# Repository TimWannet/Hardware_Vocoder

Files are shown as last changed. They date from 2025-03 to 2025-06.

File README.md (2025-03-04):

# Hardware_Vocoder

## Table of Contents
- [Introduction](#introduction)
- [Features](#features)
- [Installation](#installation)
- [Usage](#usage)
- [Contributing](#contributing)
- [License](#license)

## Introduction
Coming soon

## Features
Coming soon

## Installation
1. Clone the repository:
    ```bash
    git clone https://github.com/yourusername/Hardware_Vocoder.git
    ```
2. Navigate to the project directory:
    ```bash
    cd Hardware_Vocoder
    ```

3. Install [PlatformIO IDE](https://platformio.org/install/ide?install=vscode) for Visual Studio Code.

4. (Linux only) Install UDEV Rules

5. Open the project in Visual Studio Code.

6. Configure the `platformio.ini` file in the project directory with the following content:
    ```ini
    [env:teensy40]
    platform = teensy
    board = teensy41
    framework = arduino
    ```
7. Connect your Teensy board to your computer.

8. Build and upload the project to the Teensy board:
    ```bash
    pio run --target upload
    ```
9. Verify the installation by checking the serial monitor for output from the Teensy board.

## Usage
Coming soon 

## Contributing
Coming soon

## License
The licence for this project is still being

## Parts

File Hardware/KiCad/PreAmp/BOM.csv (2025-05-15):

Comment | Designator | Footprint | JLCPCB Part+ACM-(optional)
INA217AIDWR | U2 | INA217:DW16 | C1849416
TLV2371DBV | U1 | Package+AF8-TO+AF8-SOT+AF8-SMD:SOT+AC0-23+AC0-5 | C55940
27R | R5 | Capacitor+AF8-SMD:C+AF8-0805+AF8-2012Metric | C17594
2.2K | +ACI-R3 | R4+ACI- | Capacitor+AF8-SMD:C+AF8-0805+AF8-2012Metric | C17520
12K | R2 | Capacitor+AF8-SMD:C+AF8-0805+AF8-2012Metric | C2907225
33K | R1 | Capacitor+AF8-SMD:C+AF8-0805+AF8-2012Metric | C17633
0.1uF | +ACI-C3 | C4+ACI- | Capacitor+AF8-Tantalum+AF8-SMD:CP+AF8-EIA+AC0-3216+AC0-18+AF8-Kemet+AC0-A | C7173
47uF | +ACI-C1 | C2+ACI- | Capacitor+AF8-SMD:C+AF8-1206+AF8-3216Metric | C76659

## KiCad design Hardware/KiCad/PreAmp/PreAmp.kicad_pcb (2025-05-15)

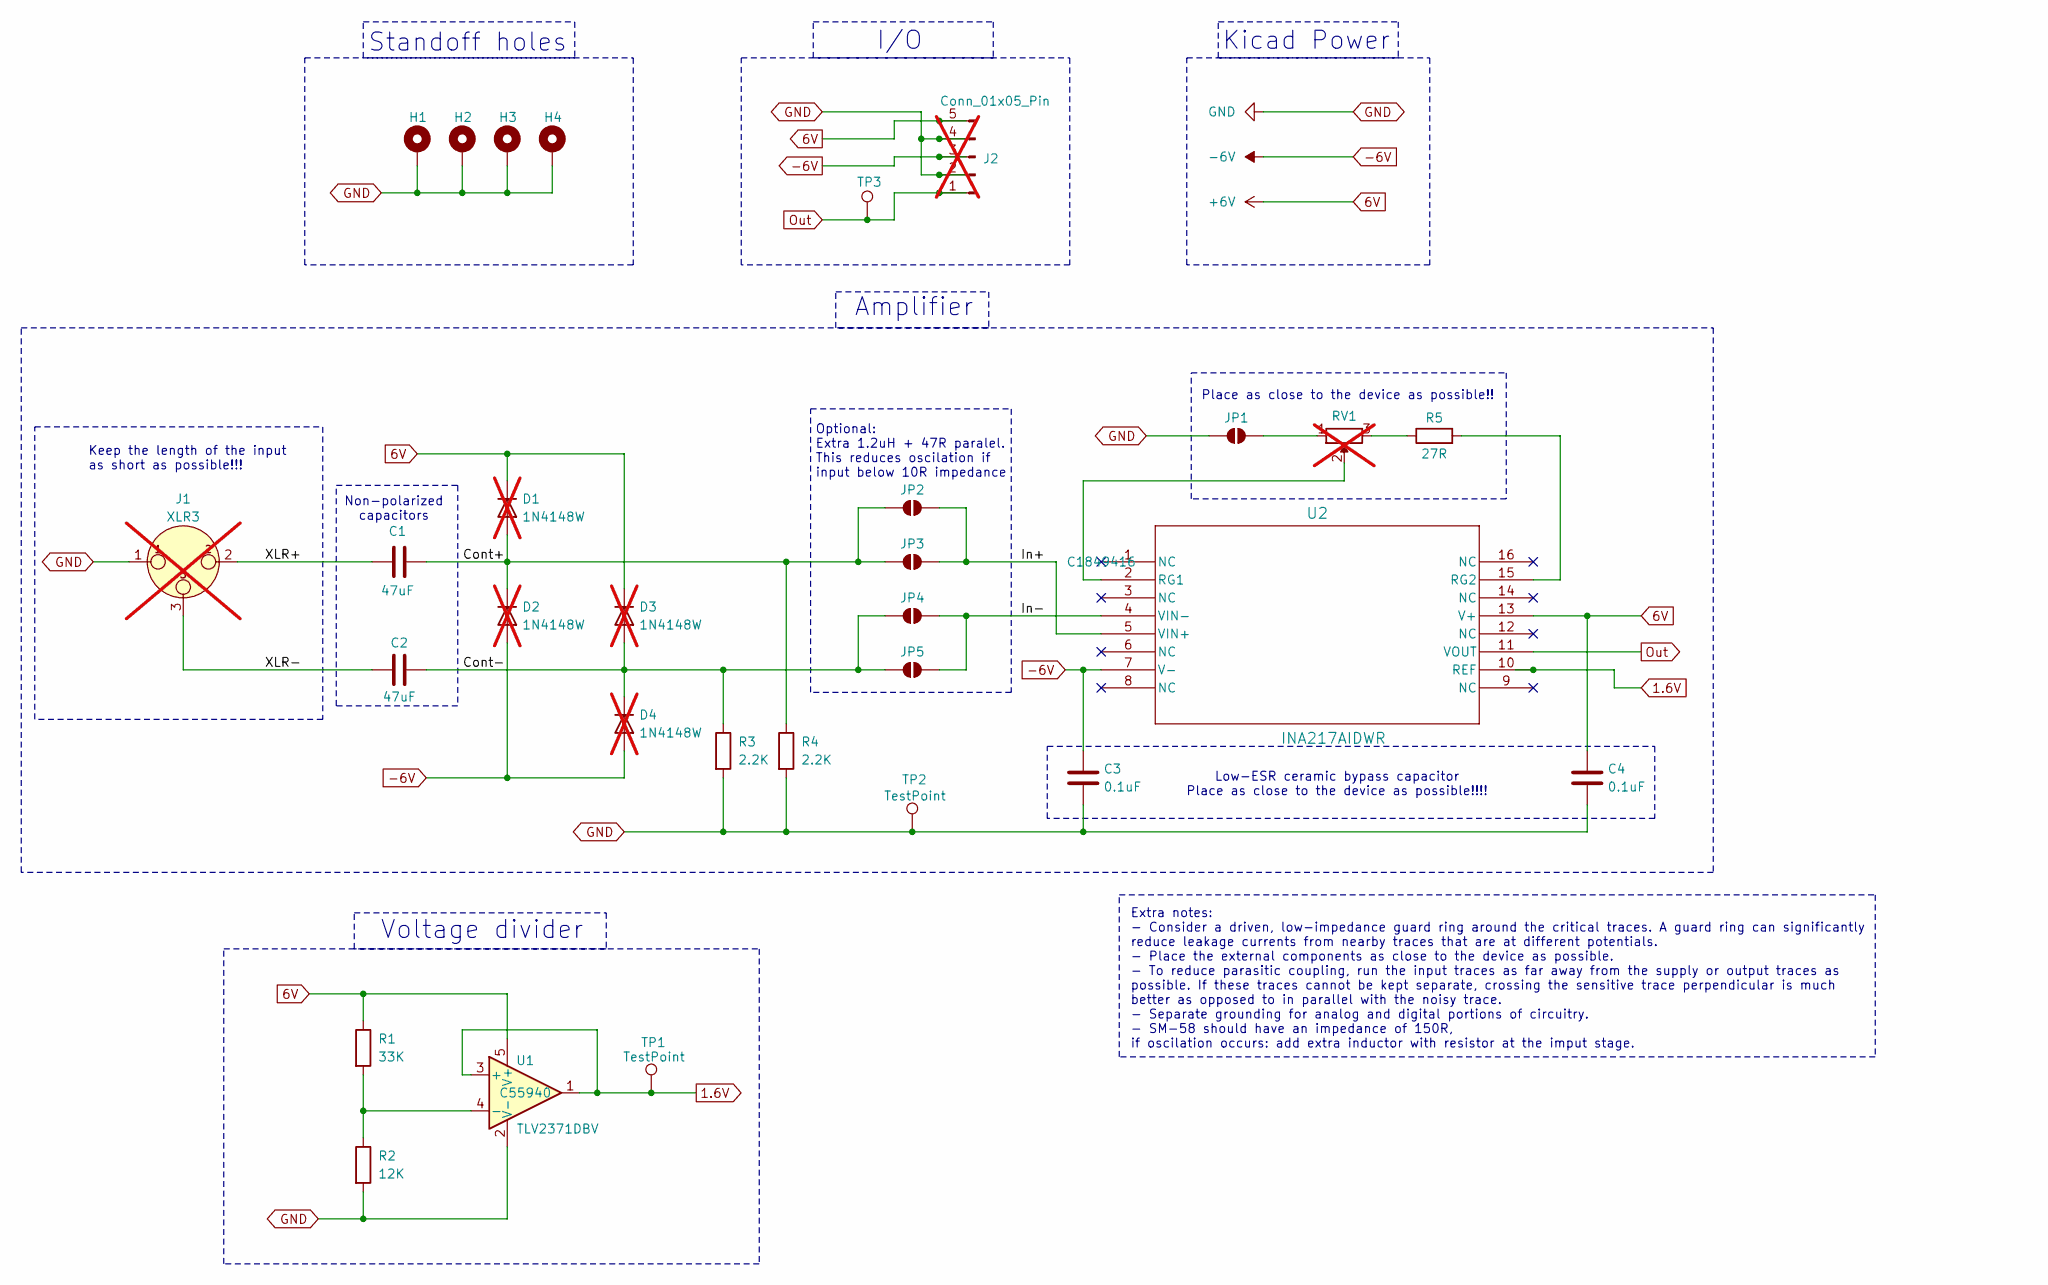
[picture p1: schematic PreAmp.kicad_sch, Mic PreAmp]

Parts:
C1, C2: 47uF; C_1206_3216Metric; LCSC PN C76659
C3, C4: 0.1uF; CP_EIA-3216-18_Kemet-A; LCSC PN C7173
D1, D2, D3, D4: 1N4148W; D_DO-35_SOD27_P7.62mm_Horizontal; not fitted
H1, H2, H3, H4: MountingHole_Pad; MountingHole_3.2mm_M3_DIN965_Pad_TopBottom
J1: XLR3; Jack_XLR_Neutrik_NC3FAAV-0_Vertical; not fitted
J2: Conn_01x05_Pin; PinHeader_1x05_P2.54mm_Vertical; not fitted
JP1, JP2, JP3, JP4, JP5: SolderJumper_2_Open; SolderJumper-2_P1.3mm_Open_Pad1.0x1.5mm
R1: 33K; C_0805_2012Metric; LCSC PN C17633
R2: 12K; C_0805_2012Metric; LCSC PN C2907225
R3, R4: 2.2K; C_0805_2012Metric; LCSC PN C17594
R5: 27R; C_0805_2012Metric; LCSC PN C17594
RV1: R_Potentiometer; Potentiometer_Alpha_RD901F-40-00D_Single_Vertical; not fitted
TP1, TP2, TP3: TestPoint; TestPoint_Pad_D2.0mm
U1: TLV2371DBV; SOT-23-5; LCSC PN C55940
U2: INA217AIDWR; DW16; LCSC PN C1849416

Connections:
1.6V: TP1.1, U1.1, U1.3 (+), U2.10 (REF)
6V: C4.1, D1.1 (K), D3.1 (K), J2.5, R1.1, U1.5 (V+), U2.13 (V+)
-6V: C3.1, D2.2 (A), D4.2 (A), J2.3, U2.7 (V-)
/Cont+: C1.2, D1.2 (A), D2.1 (K), JP2.2 (B), JP3.2 (B), R4.1
/Cont-: C2.2, D3.2 (A), D4.1 (K), JP4.2 (B), JP5.2 (B), R3.1
/In+: JP2.1 (A), JP3.1 (A), U2.5 (VIN+)
/In-: JP4.1 (A), JP5.1 (A), U2.4 (VIN-)
/XLR+: C1.1, J1.2
/XLR-: C2.1, J1.3
GND: C3.2, C4.2, H1.1, H2.1, H3.1, H4.1, J1.1, J2.2, J2.4, JP1.2 (B), R2.2, R3.2, R4.2, TP2.1, U1.2 (V-)
unnamed: JP1.1 (A), RV1.1
unnamed: R5.1, RV1.3
unnamed: R1.2, R2.1, U1.4 (-)
unnamed: RV1.2, U2.2 (RG1)
unnamed: R5.2, U2.15 (RG2)
Out: J2.1, TP3.1, U2.11 (VOUT)

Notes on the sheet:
Optional: Extra 1.2uH + 47R paralel. This reduces oscilation if input below 10R impedance
Standoff holes
Extra notes: - Consider a driven, low-impedance guard ring around the critical traces. A guard ring can significantly reduce leakage currents from nearby traces that are at different potentials. - Place the external components as close to the device as possible. - To reduce parasitic coupling, run 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
Low-ESR ceramic bypass capacitor Place as close to the device as possible!!!!
Voltage divider
Place as close to the device as possible!!
Amplifier
Kicad Power
Non-polarized capacitors
Keep the length of the input as short as possible!!!
I/O

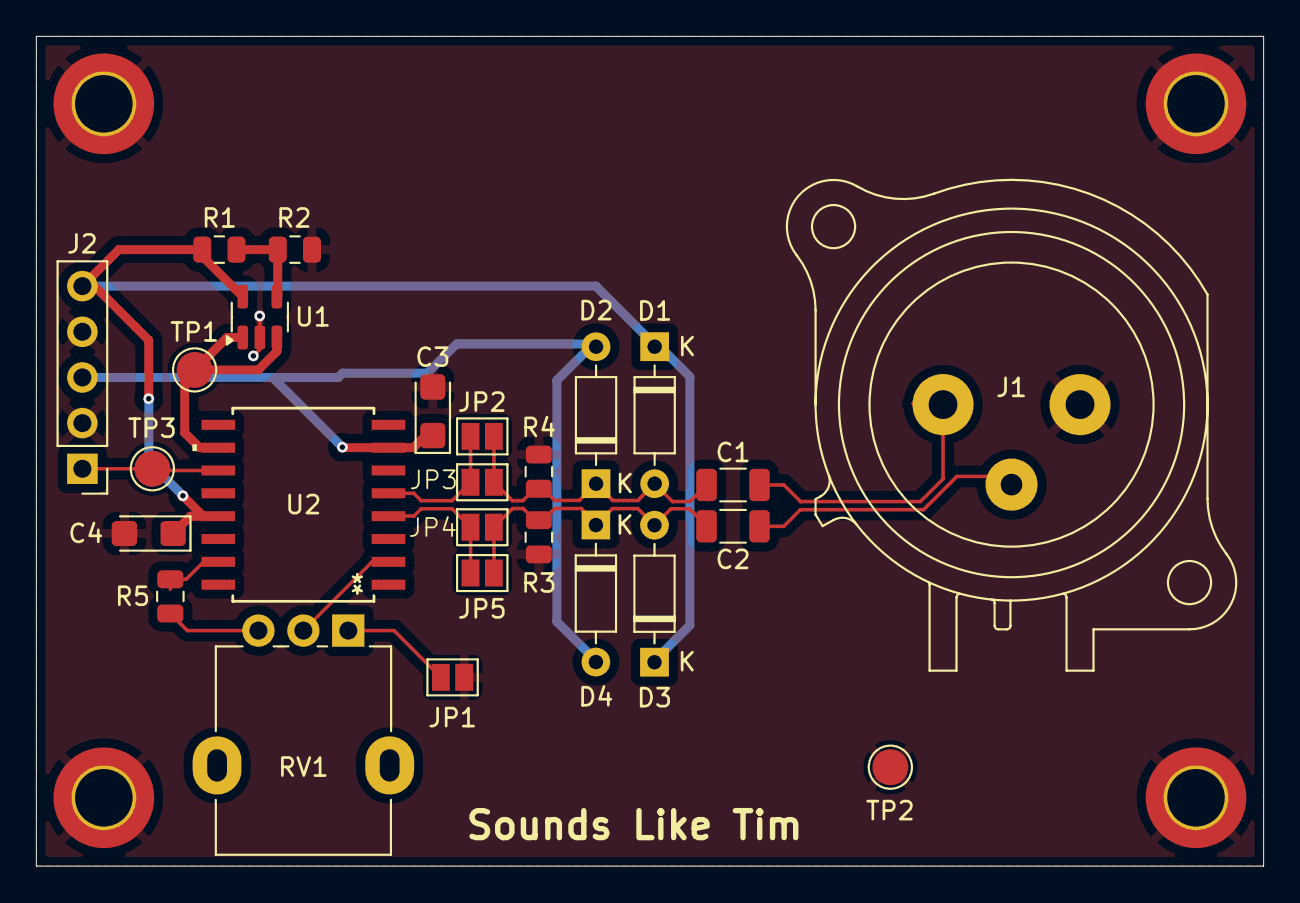
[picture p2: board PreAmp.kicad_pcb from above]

Board: 2 copper layers, 68.3 x 46.2 mm, 30 parts (0 on the bottom side), 16 nets.

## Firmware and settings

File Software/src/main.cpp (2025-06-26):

/**
 * @file main.cpp
 * @brief Hardware Vocoder Software Implementation
 * 
 * @details This program implements a hardware vocoder using the Teensy Audio Library. 
 * It processes audio signals from a carrier input and a modulator input, performs 
 * Fast Fourier Transform (FFT) analysis, and reconstructs the signal for playback.
 * 
 * The program is structured into three main processing classes:
 * - CarrierBufferProcessor: Handles audio data from the carrier input.
 * - ModulatorProcessor: Handles audio data from the modulator input.
 * - PlaybackProcessor: Handles audio data playback after processing.
 * 
 * The FFT is performed using the CMSIS-DSP library, which provides optimized 
 * FFT routines for ARM Cortex-M processors. The program extracts magnitude and 
 * phase information from the frequency domain, reconstructs the signal, and 
 * performs an inverse FFT to return to the time domain.
 * 
 * @note The FFT size can be adjusted by modifying the `FFT_SIZE` macro. Supported 
 * sizes include 128, 256, 512, 1024, 2048, and 4096.
 * 
 * @author Tim Wannet
 * @date 26-03-2025
 * @version 0.02
 */

#include "DSP/utils.h"
#include "DSP/fft_utils.h"
#include "DSP/audio_stream_classes.h"

#include "UI/input_manager.h"
#include "UI/screen_manager.h"
#include "UI/screen_main_menu.h"

// defines/constants
#define TFT_RST   28
#define TFT_DC    29
#define TFT_CS    30
#define TFT_BLK   31  
#define TFT_MOSI  26
#define TFT_CLK   27
#define ENCODER_BUTTON 35
#define ENCODER_PIN_A 34
#define ENCODER_PIN_B 33
// #define SPI_CLOCK 24000000

const int FFT_SIZE = 1024; // Buffer size (Change this value as needed: 128, 256, 512, 1024, 2048, etc.)
const arm_cfft_instance_f32* fftConfig;

// Audio Library objects
AudioInputI2S         i2sInput;  // I2S input from Audio Shield
AudioInputAnalog      analogInput(A17); // Analog input as modulator
AudioOutputI2S        i2sOutput; // I2S output to Audio Shield
AudioControlSGTL5000  sgtl5000_1;

// variables
int16_t carrierBuffer[FFT_SIZE];
int16_t modulatorBuffer[FFT_SIZE];
int16_t fftFloatBuffer[FFT_SIZE];

float fftBuffer[FFT_SIZE * 2];
float carrierFloatBuffer[FFT_SIZE * 2];
float modulatorFloatBuffer[FFT_SIZE * 2];
float modulatorFFT[FFT_SIZE * 2];
float modulatorMagnitude[FFT_SIZE];
float carrierMagnitude[FFT_SIZE];
float smoothedModulator[FFT_SIZE] = {0}; // Initialize smoothedModulator with zeros
float modulatorPhase[FFT_SIZE];
float carrierPhase[FFT_SIZE];

volatile bool carrierBufferFull = false;
volatile bool modulatorBufferFull = false;
volatile bool playbackReady = false;


//Constructors
ILI9488 tft = ILI9488(TFT_CS, TFT_DC, TFT_MOSI, TFT_CLK, TFT_RST, -1);
// Adafruit_ST7735 tft = Adafruit_ST7735(&SPI1, TFT_CS, TFT_DC, TFT_RST);

ScreenManager screenManager(tft);
// ScreenManager* screenManager;
// ScreenMainMenu mainMenu(*screenManager);
ScreenMainMenu mainMenu(&screenManager);
ScreenSettings settingsScreen(&screenManager);

InputManager inputManager(ENCODER_PIN_A, ENCODER_PIN_B, ENCODER_BUTTON);

// Audio Library objects/patch connections
CarrierBufferProcessor  carrierProcessor;
ModulatorProcessor      modulatorProcessor;
PlaybackProcessor       playbackProcessor;
AudioConnection         patchCord1(i2sInput, 0, carrierProcessor, 0); 
AudioConnection         patchCord2(analogInput, 0, modulatorProcessor, 0); 
AudioConnection         patchCord3(playbackProcessor, 0, i2sOutput, 0); // left channel
AudioConnection         patchCord4(playbackProcessor, 0, i2sOutput, 1); // right channel

 
/*
* @brief Setup function
*
* @details This function initializes the audio library and the SGTL5000 audio codec.
*/
void setup()
{
    Serial.begin(115200);

    AudioMemory(100);
    sgtl5000_1.enable();
    sgtl5000_1.inputSelect(AUDIO_INPUT_LINEIN);
    sgtl5000_1.volume(0.5);
    sgtl5000_1.inputLevel(0.5); 

    fftConfig = getFFTConfig(FFT_SIZE);
    if (!fftConfig)
    {
        Serial.println("Invalid FFT size!");
        return;
    }
    
    

    inputManager.begin();

    // Connect input events to screen manager
    inputManager.onInput([](InputEvent event) {
        screenManager.handleInput(event);
    });

    pinMode(TFT_BLK, OUTPUT);
    digitalWrite(TFT_BLK, LOW); 
    delay(2000); 
    digitalWrite(TFT_BLK, HIGH);  // Turn backlight ON

    // Initialize the TFT display
    tft.begin();
    tft.setRotation(3);
    tft.fillScreen(ILI9488_BLACK);

    mainMenu.setSettingsScreen(&settingsScreen);
    settingsScreen.setMainMenuScreen(&mainMenu);
    
    screenManager.setScreen(&mainMenu);

    Serial.println("Setup complete");
}

/*
* @brief Loop function
*
* @details This function is the main loop of the program.
* It checks if the buffer is full and processes the FFT when the buffer is full.
*/
void loop()
{
    inputManager.update();  // Reads encoder, may set needsRedraw flag
    screenManager.update(); // Optional if doing per-screen updates

    screenManager.draw();  // Only draw when something changed

    if (carrierBufferFull == true && modulatorBufferFull == true)
    {
        for (int i = 0; i < FFT_SIZE; i++) 
        {
            modulatorBuffer[i] = highpass(modulatorBuffer[i]);
        }

        // Convert int16_t to float
        convertInt16ToFloat(carrierBuffer, carrierFloatBuffer);
        convertInt16ToFloat(modulatorBuffer, modulatorFloatBuffer);

        processFFT(carrierFloatBuffer, carrierMagnitude, carrierPhase);
        processFFT(modulatorFloatBuffer, modulatorMagnitude, modulatorPhase);

        inverseFFT(fftBuffer, carrierMagnitude, carrierPhase, modulatorMagnitude, modulatorPhase);
        
        convertFloatToInt16(fftBuffer, fftFloatBuffer);

        carrierBufferFull = false;
        modulatorBufferFull = false;
        playbackReady = true;
    }
}

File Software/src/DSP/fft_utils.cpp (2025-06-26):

/**
 * @file fft_utils.cpp
 * @brief FFT utility functions
 *  
 * @details This file contains utility functions for performing FFT operations.
 * It includes functions for getting FFT configuration, extracting magnitude and phase,
 * performing inverse FFT, and processing FFT.
 *  
 * @author Tim Wannet
 * @date 20-05-2025
 * @version 0.01
 */

// Headers
#include "fft_utils.h"

// Variables
const float sampleRate = 44100.0; // Sample rate in Hz
const float cutoffFreq = 200.0; // Cutoff frequency for highpass filter

float prev_input = 0.0;
float prev_output = 0.0;
float RC = 1.0 / (2 * PI * cutoffFreq);  // e.g., 200 Hz
float dt = 1.0 / sampleRate;
float alpha = RC / (RC + dt);

float noiseUnvoiced = static_cast<float>(rand()) / RAND_MAX + 0.5f; // -0.5 to +0.5
float unvoicedNoiseStrength = 0.9f; // scale to taste
float noiseVoiced = static_cast<float>(rand()) / RAND_MAX + 0.5f;
float voicedNoiseStrength = 0.4f;
/*
* @brief Get FFT Configuration function
*
* @param[in] size The FFT size
*
* @details This function returns the FFT configuration based on the FFT size.
*/
const arm_cfft_instance_f32* getFFTConfig(int size) 
{
    switch (size)
    {
        case 128:  return &arm_cfft_sR_f32_len128;
        case 256:  return &arm_cfft_sR_f32_len256;
        case 512:  return &arm_cfft_sR_f32_len512;
        case 1024: return &arm_cfft_sR_f32_len1024;
        case 2048: return &arm_cfft_sR_f32_len2048;
        case 4096: return &arm_cfft_sR_f32_len4096;
        default:   return nullptr; // Handle error
    }
}

/*
* @brief Get Magnitude and Phase function
*
* @param[in] buffer         The audio data buffer
* @param[out] magnitude     The magnitude information
* @param[out] phase         The phase information
*
* @details This function extracts the magnitude and phase from the buffer in the frequency domain.
* The magnitude is calculated as the square root of the sum of the squares of the real and imaginary parts.
* The phase is calculated as the arctangent of the imaginary part divided by the real part.
*/
void getMagnitudeAndPhase(float *buffer, float *magnitude, float *phase)
{
    for (int i = 0; i < FFT_SIZE; i++)
    {
        float real = buffer[2 * i];
        float imag = buffer[2 * i + 1];
        magnitude[i] = sqrtf((real * real) + (imag * imag));
        phase[i] = atan2f(imag, real);
    }

    // // Debug print: Print first 8 bins of magnitude and phase
    // Serial.println("FFT Debug Output:");
    // for (int i = 0; i < 8 && i < FFT_SIZE; i++) {
    //     Serial.print("Bin ");
    //     Serial.print(i);
    //     Serial.print(": Magnitude = ");
    //     Serial.print(magnitude[i]);
    //     Serial.print(", Phase = ");
    //     Serial.println(phase[i]);
    // }
}

bool isUnvoiced(const float* magnitude) 
{
    constexpr float SAMPLE_RATE = 44100.0f;
    float BIN_WIDTH = SAMPLE_RATE / FFT_SIZE;

    // Define band ranges (you can tune these further)
    const int lowStart = (int)(80 / BIN_WIDTH);
    const int lowEnd   = (int)(500 / BIN_WIDTH);

    const int highStart = (int)(3000 / BIN_WIDTH);
    const int highEnd   = (int)(8000 / BIN_WIDTH);

    float lowEnergy = 0.0f;
    float highEnergy = 0.0f;

    for (int i = lowStart; i < lowEnd; i++) {
        lowEnergy += magnitude[i];
    }

    for (int i = highStart; i < highEnd; i++) {
        highEnergy += magnitude[i];
    }

    // Avoid divide-by-zero
    if (lowEnergy < 1e-5f) lowEnergy = 1e-5f;

    float ratio = highEnergy / lowEnergy;

    // try values between 3.0 and 6.0
    return (ratio > 5.0f);
}

/*
* @brief Inverse FFT function
*
* @param[in] buffer             The audio data buffer
* @param[in] carrierMagnitude   The carrier magnitude information
* @param[in] carrierPhase       The carrier phase information
* @param[in] modulatorMagnitude The modulator magnitude information
* @param[in] modulatorPhase     The modulator phase information
*
* @details This function reconstructs the signal from the magnitude and phase information.
* It then performs an inverse FFT to return to the time domain.
*/
void inverseFFT(float *buffer, float *carrierMagnitude, float *carrierPhase, float *modulatorMagnitude, float *modulatorPhase)
{

    float lowEnergy = 0.0f;
    float highEnergy = 0.0f;

    for (int i = 0; i < FFT_SIZE / 2; i++) {
        if (i < FFT_SIZE / 16) { // Low frequencies (e.g. ~0–500Hz)
            lowEnergy += modulatorMagnitude[i];
        } else if (i > FFT_SIZE / 10) { // High frequencies (e.g. >1kHz)
            highEnergy += modulatorMagnitude[i];
        }
    }

    // bool isUnvoiced = (highEnergy > lowEnergy * 1.0f) && (highEnergy > 0.01f);
    bool is_unvoiced = isUnvoiced(modulatorMagnitude);

    if (is_unvoiced) 
    {
        for (int i = 0; i < FFT_SIZE / 2; i++) 
        {
            buffer[2 * i] = noiseUnvoiced * unvoicedNoiseStrength; // real
            buffer[2 * i + 1] = noiseUnvoiced * unvoicedNoiseStrength; // imaginary
        }
    }
    else
    {
        for (int i = 0; i < FFT_SIZE; i++) 
        {
            float normalizedMod = modulatorMagnitude[i] / 32768.0f; 
            float normalizedCarrier = carrierMagnitude[i] / 32768.0f;
            float fftMagnitude = normalizedCarrier * pow(normalizedMod, 0.7f) * 32768.0f; // Scale back
            fftMagnitude += noiseVoiced * voicedNoiseStrength * 32768.0f; // Add noise to voiced signal 

            buffer[2 * i] = fftMagnitude * cosf(carrierPhase[i]); // Real part
            buffer[2 * i + 1] = fftMagnitude * sinf(carrierPhase[i]); // Imaginary part
        }
    }
    // Perform Inverse FFT
    arm_cfft_f32(fftConfig, buffer, 1, 1);

}

/*
* @brief Process FFT function
*
* @param[in] buffer         The audio data buffer
* @param[in] floatBuffer    The float buffer
* @param[out] magnitude     The magnitude information
* @param[out] phase         The phase information 
*
* @details This function performs the FFT on the audio data in the buffer.
* It converts the audio data to float, performs the FFT, and extracts the magnitude and phase information.
*/
void processFFT(float *floatBuffer, float *magnitude, float *phase)
{
    // Perform FFT
    arm_cfft_f32(fftConfig, floatBuffer, 0, 1);
    
    // Extract magnitude and phase
    getMagnitudeAndPhase(floatBuffer, magnitude, phase);

}

/*
* @brief Highpass filter function
*
* @param[in] input The input audio data
* @return The filtered output
*
* @details This function implements a simple highpass filter using a single pole IIR filter.
* The filter is designed to remove low-frequency components from the audio signal.
*/
float highpass(int16_t input)
{
    float output = alpha * (prev_output + input - prev_input);
    prev_input = input;
    prev_output = output;
    return output;
}

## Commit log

2025-03-10 Fix fft bug, fix input logic & implement sgtl5000_1 Audio shield
    [main.cpp]
2025-03-12 Inverse FFT for Carrier working (only for 128 samples), organised code
2025-03-24 Complete re-design of the code, now with Interrupts to handle sampling and transfer. /bugfix for the FFT_SIZE
    [main.cpp]
2025-03-26 Switch case function for different fft sizes with arm_cfft_sR_f32_len128
2025-03-27 new function prototype
2025-03-27 correction for renaming variables
    [main.cpp]
2025-03-31 Bugfix -> reset index to get proper values
    [main.cpp]
2025-04-03 created Hardware file
    [Hardware.kicad_pcb, Hardware.kicad_sch]
2025-04-03 Created titles
    [Hardware.kicad_sch, PreAmp.kicad_sch]
2025-04-03 Imported OPA1656 into project and library
    [PreAmp.kicad_sch]
2025-04-09 Implemented High Pass filter function
2025-04-09 Schematic with 2 opamps, XLR to onewire (Need: tested & grounded)
2025-04-09 Re-organised schematic and simulation in own directory
    [Hardware.kicad_pcb, Hardware.kicad_sch, PreAmp.kicad_sch]
2025-04-15 V1 Microphone circuit (simulated in LTSpice)
2025-04-15 created 5V USB-C Power supply (simple version for now)
2025-04-15 Hierarchical sheet for MCU
    [Hardware.kicad_sch, MCU.kicad_sch, PSU.kicad_sch]
2025-04-16 Midi in circuit with optocoupler and isolation/input protection
    [Hardware.kicad_sch, I_O.kicad_sch]
2025-04-16 Labeled, sheet out from modulator
    [Hardware.kicad_sch, I_O.kicad_sch]
2025-05-06 V1 for the schematic (Looks promising)
    [OPA137.DSN]
2025-05-07 Excanged Opamp for TVL2371
    [tlv2371.dsn]
2025-05-07 Created seperate KiCad for PreAmp
    [PreAmp.kicad_pcb, PreAmp.kicad_sch]
2025-05-07 Header pins for input and output
    [PreAmp.kicad_sch]
2025-05-07 Inserted XLR plug
    [PreAmp.kicad_sch]
2025-05-07 created XLR input
    [PreAmp.kicad_sch]
2025-05-07 Voltage divider circuit
    [PreAmp.kicad_sch]
2025-05-07 Circuit before V_In
    [PreAmp.kicad_sch]
2025-05-07 Connected REF and Output
    [PreAmp.kicad_sch]
2025-05-07 Reorganised+rename Main_Board project
    [I_O.kicad_sch, MCU.kicad_sch, Main_Board.kicad_pcb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]
2025-05-07 Relocated PreAmp project
    [PreAmp.kicad_pcb, PreAmp.kicad_sch]
2025-05-07 Potmeter for amplification
    [PreAmp.kicad_sch]
2025-05-07 Datasheet comments + extra test points added
    [PreAmp.kicad_sch]
2025-05-08 Imported PCB components
2025-05-08 Changed flow -> right to left
    [PreAmp.kicad_pcb, PreAmp.kicad_sch]
2025-05-08 Layout everything globaly
    [PreAmp.kicad_pcb]
2025-05-08 Changed Header pin
    [PreAmp.kicad_sch]
2025-05-08 First layout
    [PreAmp.kicad_pcb]
2025-05-08 Equal length traces for Hot and Cold
    [PreAmp.kicad_pcb]
2025-05-08 First part of differential routing
    [PreAmp.kicad_pcb, PreAmp.kicad_sch]
2025-05-08 Removed 4 jumper points
    [PreAmp.kicad_pcb, PreAmp.kicad_sch]
2025-05-08 Connected everything together
    [PreAmp.kicad_pcb]
2025-05-08 Lower ground plane
    [PreAmp.kicad_pcb]
2025-05-08 V1 done
    [PreAmp.kicad_pcb]
2025-05-08 Added version number and date
    [PreAmp.kicad_pcb]
2025-05-09 Put back the 4 jumpers for possible improvement (reduce oscilation)
    [PreAmp.kicad_pcb, PreAmp.kicad_sch]
2025-05-09 Improved trough feedback Tijmen
    [PreAmp.kicad_pcb]
2025-05-09 Included text on PCB
    [BOM.csv, PreAmp.kicad_pcb, PreAmp.kicad_sch]
2025-05-12 Generated files for production
    [BOM.csv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]
2025-05-12 Corrected collums
    [BOM.csv]
2025-05-15 Send to production
    [BOM.csv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]
2025-05-26 created input manager for encoder input
2025-05-26 added encoder
2025-06-24 Noise function with voice and unvoice options
    [fft_utils.cpp, main.cpp]
2025-06-26 Noise parameters, now with select and confirm option
    [main.cpp]
